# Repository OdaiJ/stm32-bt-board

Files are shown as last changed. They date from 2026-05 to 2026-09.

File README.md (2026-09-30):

# STM32 Bluetooth Demo Board

## Overview

A demo board I made as a project to learn PCB design fundamentals. The board is missing
some key features that make it general purpose; like headers for the unused MCU pins, however, it was a fun little project that took me a few months :)

This board was designed according to Phil's Lab's amazing videos on YouTube.

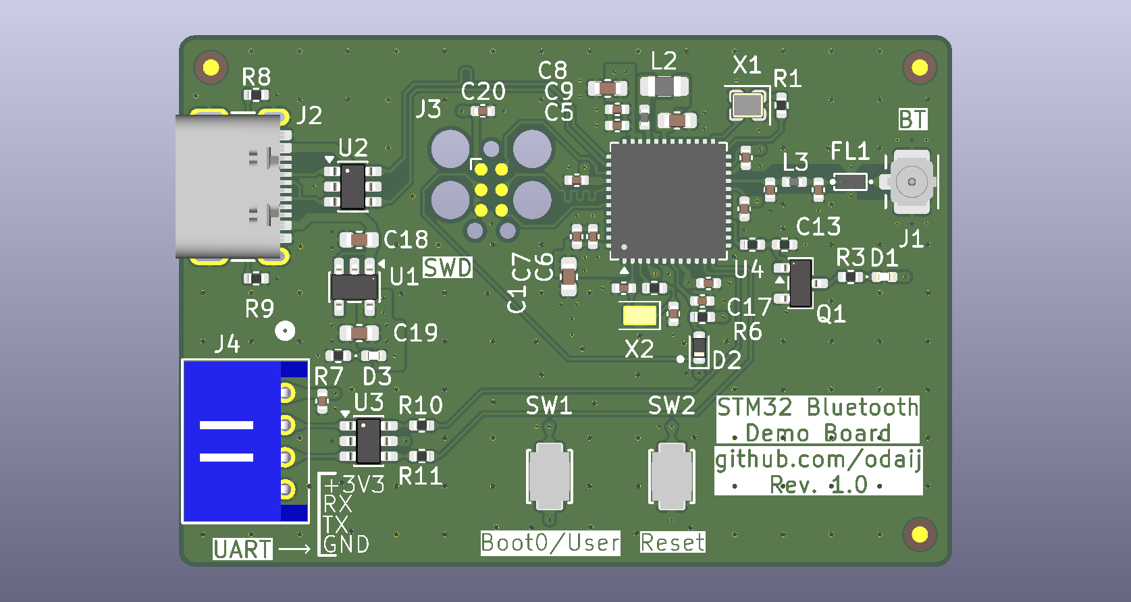
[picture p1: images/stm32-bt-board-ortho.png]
image depicting the top-down view of the board


Click here to view it on 

## Todos

1. More careful choice of components for BOM; as the MOQ is too high for most components as of now.

## Notes

Assembly PDFs are broken - KiCad won't export them correctly for some reason.

Also, as of now, I had to manually edit the CPL file so JLCPCB doesn't cry about it. P.S.: I do NOT recommend using the the JLCPCB Fabrication Tool KiCad plugin; because it didn't work for me - but that was probably my fault though.

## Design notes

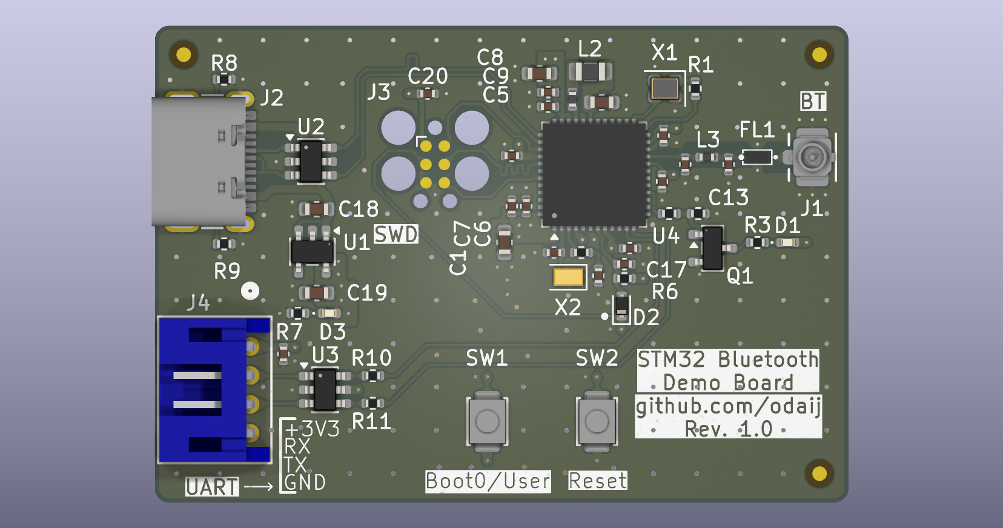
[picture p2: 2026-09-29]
images/stm32-bt-board-raytracing-ortho.png

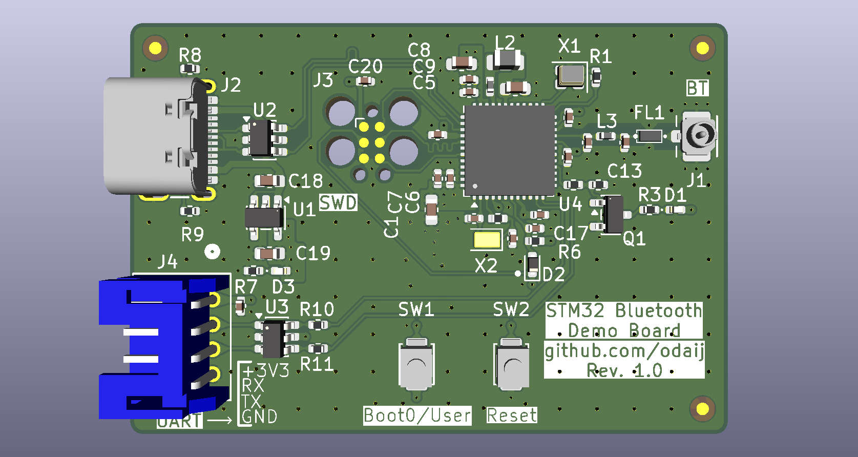
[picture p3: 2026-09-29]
images/stm32-bt-board.png

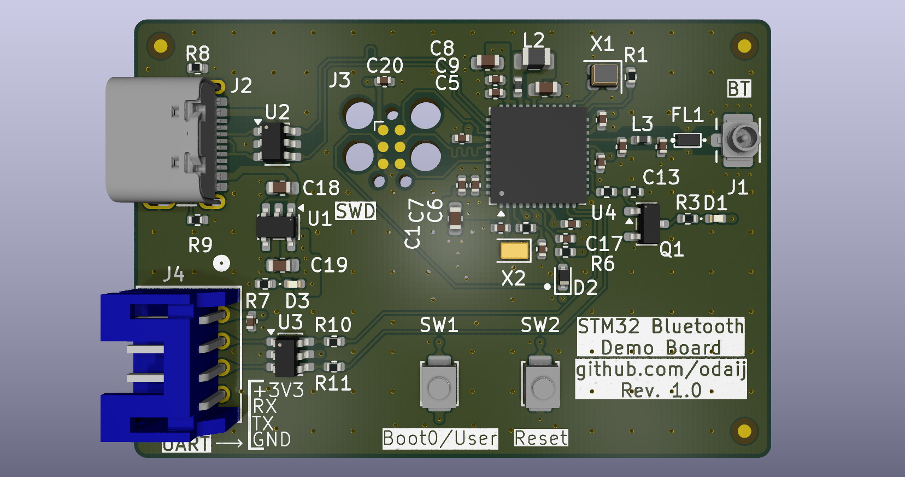
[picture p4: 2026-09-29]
images/stm32-bt-board-raytracing.png

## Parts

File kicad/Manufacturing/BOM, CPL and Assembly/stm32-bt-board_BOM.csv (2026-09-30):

Reference | Qty | Value | DNP | Exclude from BOM | Exclude from Board | Footprint | Datasheet | Distributor | Distributor Link | JLCPCB Part # | Manufacturer | MPN | Description
Q1 | 1 | S9013-E |  |  |  | Package_TO_SOT_SMD:SOT-23 | https://www.lcsc.com/datasheet/C41371419.pdf | LCSC | https://www.lcsc.com/product-detail/C41371419.html | C41371419 | MDD(Microdiode Semiconductor) | S9013-E | TRANS NPN 25V 0.5A SOT-23
X2 | 1 | 32kHz768 |  |  |  | Crystal:Crystal_SMD_2012-2Pin_2.0x1.2mm | https://www.lcsc.com/datasheet/C891748.pdf | LCSC | https://www.lcsc.com/product-detail/C891748.html | C891748 | NDK | NX2012SA-32.768KHZ-STD-MUB-2 | CRYSTAL 32.768kHz SMD
X1 | 1 | 32MHz |  |  |  | Crystal:Crystal_SMD_2016-4Pin_2.0x1.6mm | https://www.lcsc.com/datasheet/C5441424.pdf | LCSC | https://www.lcsc.com/product-detail/C5441424.html | C5441424 | NDK | NX2016SA-32MHZ-EXS00A-CS06654 | CRYSTAL 32MHz 8pF SMD
U4 | 1 | STM32WB55CEU6 |  |  |  | Package_DFN_QFN:QFN-48-1EP_7x7mm_P0.5mm_EP5.6x5.6mm | https://www.st.com/resource/en/datasheet/stm32wb55ce.pdf | LCSC | https://www.lcsc.com/product-detail/C911135.html | C911135 | ST | STM32WB55CEU6 | STMicroelectronics Arm Cortex-M4 MCU, 512KB flash, 256KB RAM, 64 MHz, 1.71-3.6V, 30 GPIO, UFQFPN48
U2,U3 | 2 | USBLC6-2SC6 |  |  |  | Package_TO_SOT_SMD:SOT-23-6 | https://www.st.com/resource/en/datasheet/usblc6-2.pdf | LCSC | https://www.lcsc.com/product-detail/C7519.html | C7519 | ST | USBLC6-2SC6 | Very low capacitance ESD protection diode, 2 data-line, SOT-23-6
U1 | 1 | MIC5365-3.3YD5 |  |  |  | Package_TO_SOT_SMD:TSOT-23-5 | https://ww1.microchip.com/downloads/aemDocuments/documents/APID/ProductDocuments/DataSheets/MIC5365-6-High-Performance-Single-150mA-LDO-DS20006605A.pdf | LCSC | https://www.lcsc.com/product-detail/C626098.html | C626098 | MICROCHIP | MIC5365-3.3YD5-TR | 150mA Low-dropout Voltage Regulator, Vout 3.3V, Vin up to 5.5V, TSOT-23-5
SW1,SW2 | 2 | B3U-1000P |  |  |  | #stm32-bt-board-external-footprints:B3U-1000P | https://www.lcsc.com/datasheet/C231329.pdf | LCSC | https://www.lcsc.com/product-detail/C231329.html | C231329 | OMRON | B3U-1000P | SWITCH TACTILE SPST 153gf SMD
R6 | 1 | 100k |  |  |  | Resistor_SMD:R_0402_1005Metric | https://www.lcsc.com/datasheet/C60491.pdf | LCSC | https://www.lcsc.com/product-detail/C60491.html | C60491 | YAGEO | RC0402FR-07100KL | RES 100kΩ ±1% 62.5mW 0402
R5,R8,R9,R13,R16 | 5 | 5k1 |  |  |  | Resistor_SMD:R_0402_1005Metric | https://www.lcsc.com/datasheet/C105872.pdf | LCSC | https://www.lcsc.com/product-detail/C105872.html | C105872 | YAGEO | RC0402FR-075K1L | RES 5.1kΩ ±1% 62.5mW 0402
R4,R7,R10,R11 | 4 | 220R |  |  |  | Resistor_SMD:R_0402_1005Metric | https://www.lcsc.com/datasheet/C2909336.pdf | LCSC | https://www.lcsc.com/product-detail/C2909336.html | C2909336 | FOJAN | FRC0402F2200TS | RES 220Ω ±1% 62.5mW 0402
R1,R2,R3 | 3 | 0R |  |  |  | Resistor_SMD:R_0402_1005Metric | https://www.lcsc.com/datasheet/C190119.pdf | LCSC | https://www.lcsc.com/product-detail/C190119.html | C190119 | VISHAY | CRCW04020000Z0ED | RES 0Ω 62.5mW 0402
L3 | 1 | 2n7 |  |  |  | Inductor_SMD:L_0402_1005Metric | https://www.lcsc.com/datasheet/C77108.pdf | LCSC | https://www.lcsc.com/product-detail/C77108.html | C77108 | muRata | LQG15HS2N7S02D | FIXED IND 2.7nH 800mA 120mΩ 0402
L2 | 1 | 10u |  |  |  | Inductor_SMD:L_0805_2012Metric | https://www.lcsc.com/datasheet/C162582.pdf | LCSC | https://www.lcsc.com/product-detail/C162582.html | C162582 | muRata | LQM21FN100M80L | FIXED IND 10uH 100mA 390mΩ 0805
L1 | 1 | 10n |  |  |  | Inductor_SMD:L_0402_1005Metric | https://www.lcsc.com/datasheet/C3911026.pdf | LCSC | https://www.lcsc.com/product-detail/C3911026.html | C3911026 | muRata | LQG15WZ10NJ02D | FIXED IND 10nH 500mA 190mΩ 0402
J4 | 1 | S4B-PH-K-S(LF)(SN) |  |  |  | #stm32-bt-board-external-footprints:S4B-PH-K-S(LF)(SN) | https://www.lcsc.com/datasheet/C157926.pdf | LCSC | https://www.lcsc.com/product-detail/C157926.html | C157926 | JST | S4B-PH-K-S(LF)(SN) | CONN HEADER TH R/A 4POS 2mm
J2 | 1 | 2171790001 |  |  |  | #stm32-bt-board-external-footprints:2171790001 | https://www.molex.com/content/dam/molex/molex-dot-com/products/automated/en-us/salesdrawingpdf/217/217179/2171790001_sd.pdf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\ | LCSC | https://www.lcsc.com/product-detail/C3197684.html | C3197684 | MOLEX | 2171790001 | TYPE C 16 PIN TOP MOUNT SMT
J1 | 1 | 1909763-1 |  |  |  | #stm32-bt-board-external-footprints:1909763-1 | https://www.lcsc.com/datasheet/C392444.pdf | LCSC | https://www.lcsc.com/product-detail/C392444.html | C392444 | TE Connectivity | 1909763-1 | CONN RCPT IPEX 50Ω SMD
FL1 | 1 | DLF162500LT-5028A1 |  |  |  | #stm32-bt-board-external-footprints:DLF162500LT-5028A1 | https://product.tdk.com/en/system/files/dam/doc/product/rf/rf/filter/catalog/rf_lpf_dlf162500lt-5028a1_en.pdf | LCSC | https://www.lcsc.com/product-detail/C531364.html | C531364 | TDK | DLF162500LT-5028A1 | Multilayer Low Pass Filter For 2400-2500MHz
D3 | 1 | VLMS1500-GS08 |  |  |  | LED_SMD:LED_0402_1005Metric | https://www.lcsc.com/datasheet/C511370.pdf | LCSC | https://www.lcsc.com/product-detail/C511370.html | C511370 | VISHAY | VLMS1500-GS08 | LED RED 0402 SMD
D2 | 1 | BAT54K |  |  |  | Diode_SMD:D_SOD-523 | https://www.lcsc.com/datasheet/C283259.pdf | LCSC | https://www.lcsc.com/product-detail/C283259.html | C283259 | ST | BAT54KFILM | DIODE SCHOTTKY 40V SOD-523
D1 | 1 | VLMB1500-GS08 |  |  |  | LED_SMD:LED_0402_1005Metric | https://www.lcsc.com/datasheet/C511042.pdf | LCSC | https://www.lcsc.com/product-detail/C511042.html | C511042 | VISHAY | VLMB1500-GS08 | LED BLUE 0402 SMD
C14,C15 | 2 | 10p |  |  |  | Capacitor_SMD:C_0402_1005Metric | https://www.lcsc.com/datasheet/C161520.pdf | LCSC | https://www.lcsc.com/product-detail/C161520.html | C161520 | muRata | GRM1555C1H100FA01D | CAP CER 10pF 50V C0G 0402
C13 | 1 | 0p3 |  |  |  | Capacitor_SMD:C_0402_1005Metric | https://www.lcsc.com/datasheet/C92338.pdf | LCSC | https://www.lcsc.com/product-detail/C92338.html | C92338 | muRata | GRM1555C1HR30WA01D | CAP CER 0.3pF 50V C0G 0402
C12 | 1 | 0p8 |  |  |  | Capacitor_SMD:C_0402_1005Metric | https://www.lcsc.com/datasheet/C76988.pdf | LCSC | https://www.lcsc.com/product-detail/C76988.html | C76988 | muRata | GRM1555C1HR80BA01D | CAP CER 0.8pF 50V C0G 0402
C2,C3,C4,C5,C6,C7,C9,C10,C16,C17,C20,C21 | 12 | 100n |  |  |  | Capacitor_SMD:C_0402_1005Metric | https://www.lcsc.com/datasheet/C60474.pdf | LCSC | https://www.lcsc.com/product-detail/C60474.html | C60474 | YAGEO | CC0402KRX7R7BB104 | CAP CER 100nF 16V X7R 0402
C1,C8,C11,C18,C19 | 5 | 4u7 |  |  |  | Capacitor_SMD:C_0603_1608Metric | https://www.lcsc.com/datasheet/C307467.pdf | LCSC | https://www.lcsc.com/product-detail/C307467.html | C307467 | Samsung Electro-Mechanics | CL10A475KL8NRNC | CAP CER 4.7uF 35V X5R 0603

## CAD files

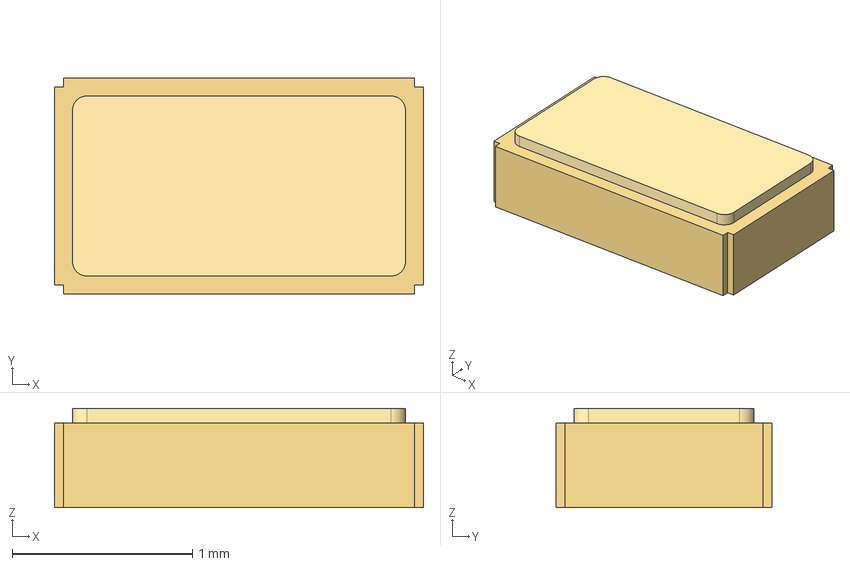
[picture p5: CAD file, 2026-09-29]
kicad/#stm32-bt-board-external-3d-models/NX2012SA-32.768KHZ-STD-MUB-2.step
2.05 x 1.20 x 0.55 mm
lid

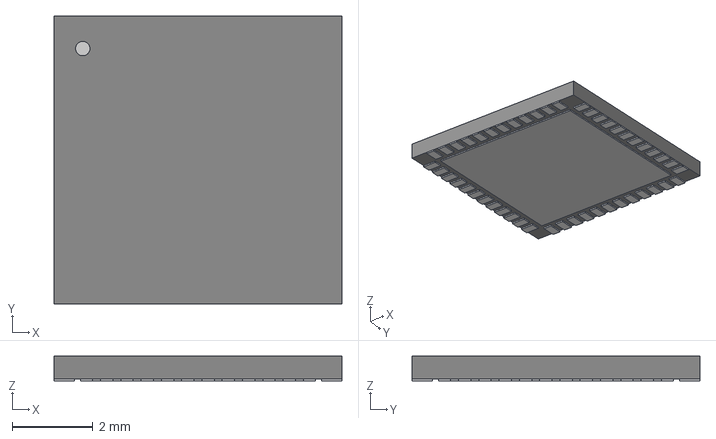
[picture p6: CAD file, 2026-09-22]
kicad/#stm32-bt-board-external-3d-models/STM32WB55CEU6.step
7.11 x 7.11 x 0.612 mm

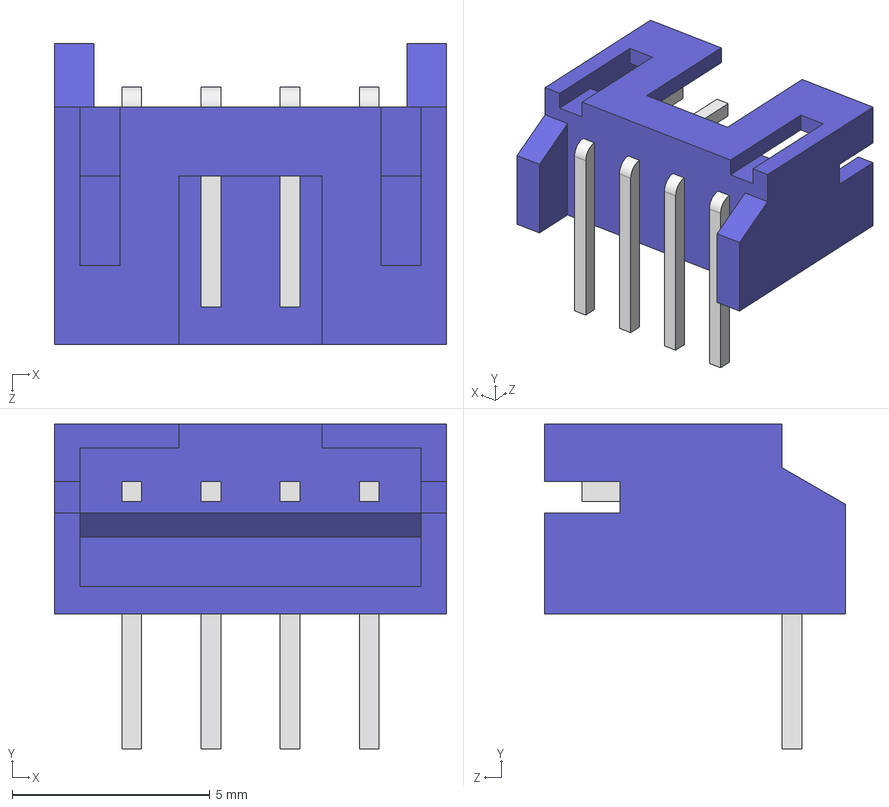
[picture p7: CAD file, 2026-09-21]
kicad/#stm32-bt-board-external-3d-models/S4B-PH-K-S(LF)(SN).STEP
9.90 x 8.20 x 7.60 mm

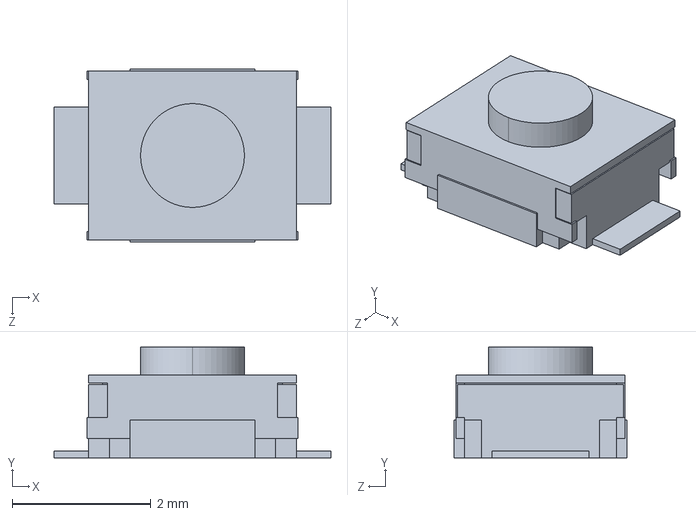
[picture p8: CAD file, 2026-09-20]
kicad/#stm32-bt-board-external-3d-models/B3U-1000P.step
4.00 x 1.60 x 2.50 mm

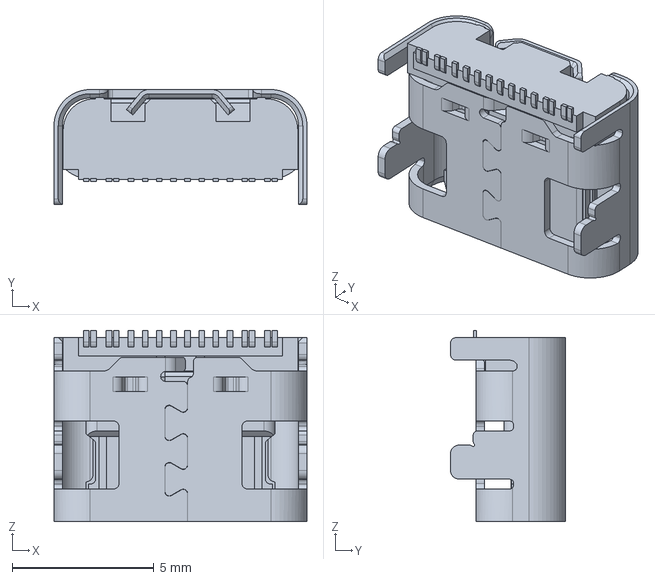
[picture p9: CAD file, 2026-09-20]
kicad/#stm32-bt-board-external-3d-models/2171790001.stp
8.94 x 4.06 x 6.75 mm

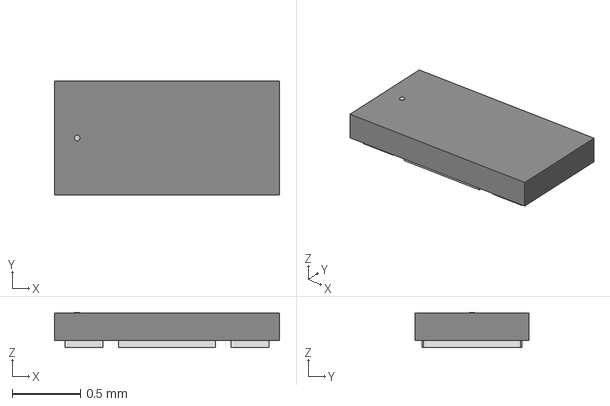
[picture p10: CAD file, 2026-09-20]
kicad/#stm32-bt-board-external-3d-models/DLF162500LT-5028A1.step
1.65 x 0.838 x 0.257 mm

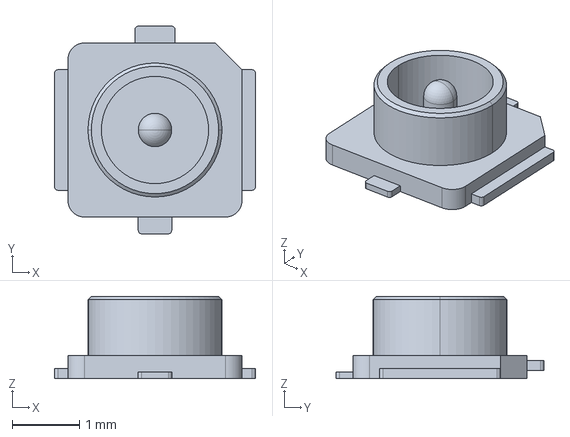
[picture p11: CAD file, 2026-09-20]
kicad/#stm32-bt-board-external-3d-models/1909763-1.stp
3.00 x 3.10 x 1.23 mm

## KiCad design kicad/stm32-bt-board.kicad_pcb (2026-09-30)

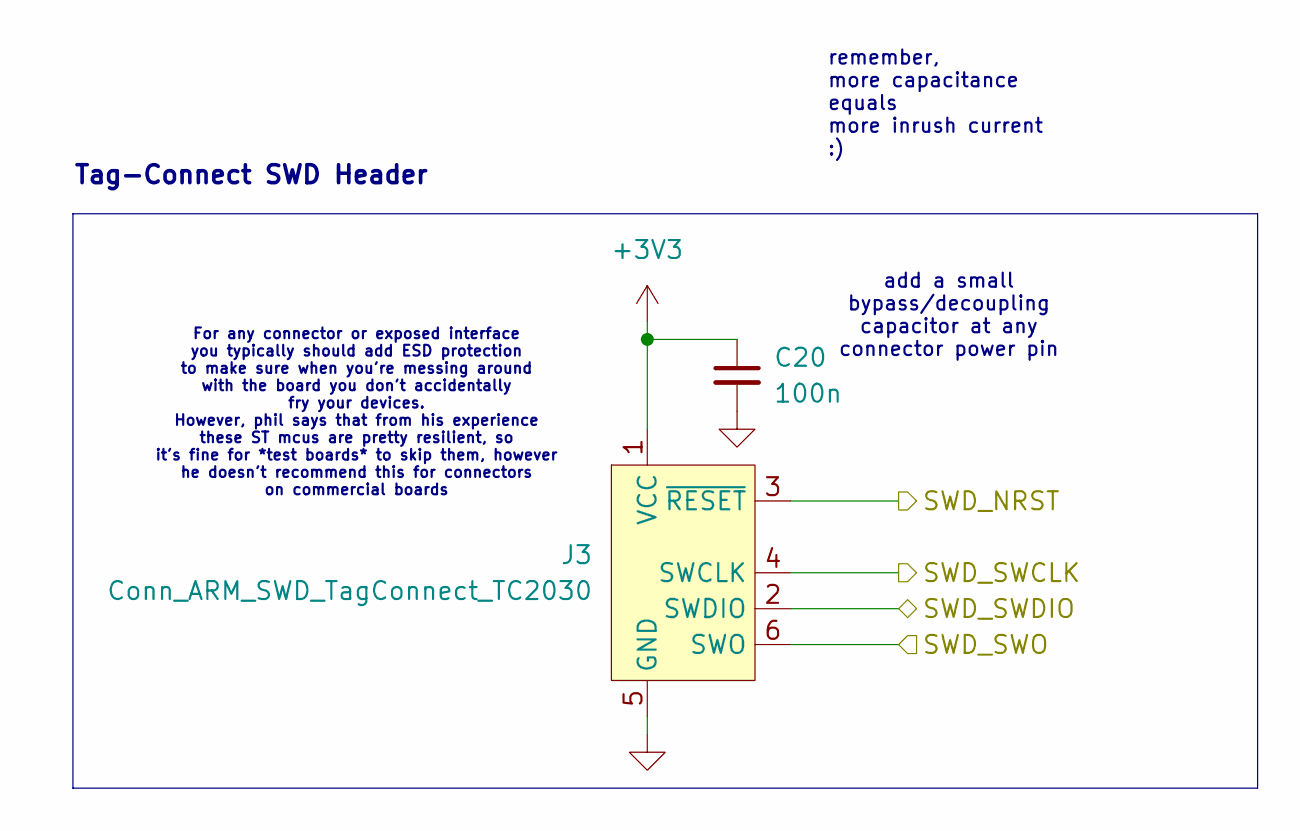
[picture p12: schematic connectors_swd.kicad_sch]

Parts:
C20: 100n; C_0402_1005Metric; MPN CC0402KRX7R7BB104
J3: Conn_ARM_SWD_TagConnect_TC2030; Tag-Connect_TC2030-IDC-FP_2x03_P1.27mm_Vertical

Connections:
+3V3: C20.1, J3.1 (VCC); also elsewhere on the board
/SWD_SWCLK: J3.4 (SWCLK); also elsewhere on the board
/SWD_SWDIO: J3.2 (SWDIO); also elsewhere on the board
/SWD_SWO: J3.6 (SWO); also elsewhere on the board
GND: C20.2, J3.5 (GND); also elsewhere on the board
NRST_IN: J3.3 (~RESET); also elsewhere on the board

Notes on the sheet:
remember, more capacitance equals more inrush current :)
For any connector or exposed interface you typically should add ESD protection to make sure when you're messing around with the board you don't accidentally fry your devices. However, phil says that from his experience these ST mcus are pretty resilient, so it's fine for *test boards* to skip them,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
Tag-Connect SWD Header
add a small bypass/decoupling capacitor at any connector power pin

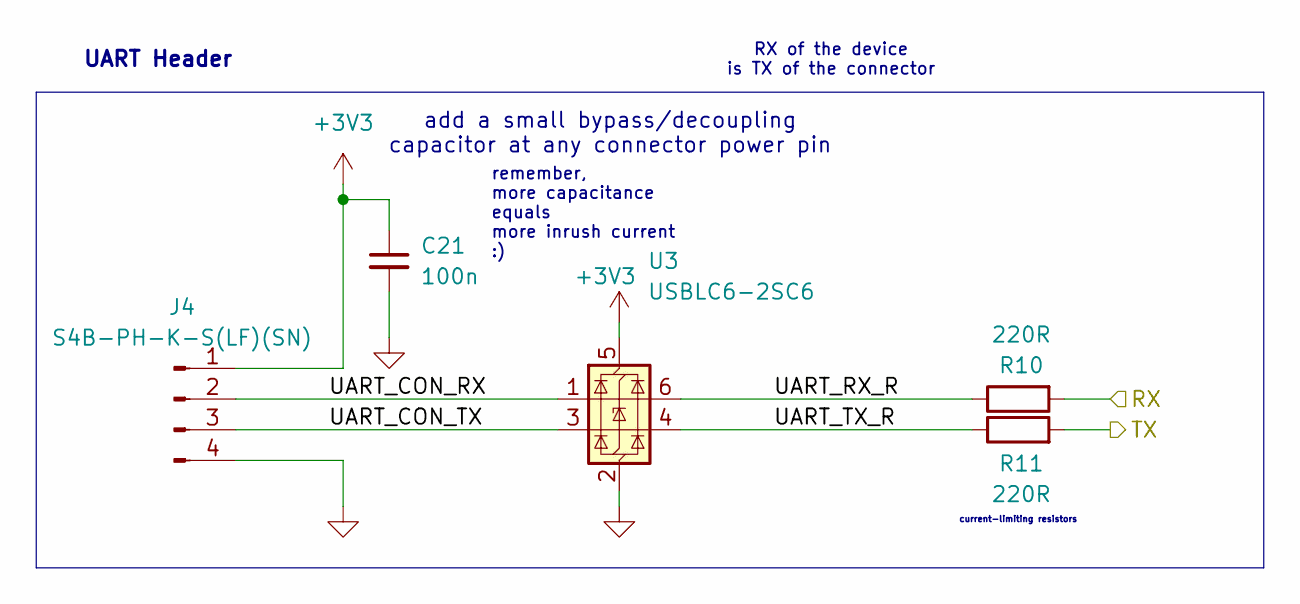
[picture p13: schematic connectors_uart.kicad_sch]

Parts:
C21: 100n; C_0402_1005Metric; MPN CC0402KRX7R7BB104
J4: S4B-PH-K-S(LF)(SN); MPN S4B-PH-K-S(LF)(SN)
R10, R11: 220R; R_0402_1005Metric; MPN FRC0402F2200TS
U3: USBLC6-2SC6; SOT-23-6; MPN USBLC6-2SC6

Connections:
+3V3: C21.1, J4.1, U3.5 (VBUS); also elsewhere on the board
/Connectors/UART/UART_CON_RX: J4.2, U3.1 (I/O1)
/Connectors/UART/UART_CON_TX: J4.3, U3.3 (I/O2)
/Connectors/UART/UART_RX_R: R10.1, U3.6 (I/O1)
/Connectors/UART/UART_TX_R: R11.1, U3.4 (I/O2)
/UART_MCU_RX: R11.2; also elsewhere on the board
/UART_MCU_TX: R10.2; also elsewhere on the board
GND: C21.2, J4.4, U3.2 (GND); also elsewhere on the board

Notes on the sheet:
remember, more capacitance equals more inrush current :)
add a small bypass/decoupling capacitor at any connector power pin
UART Header
RX of the device is TX of the connector
current-limiting resistors

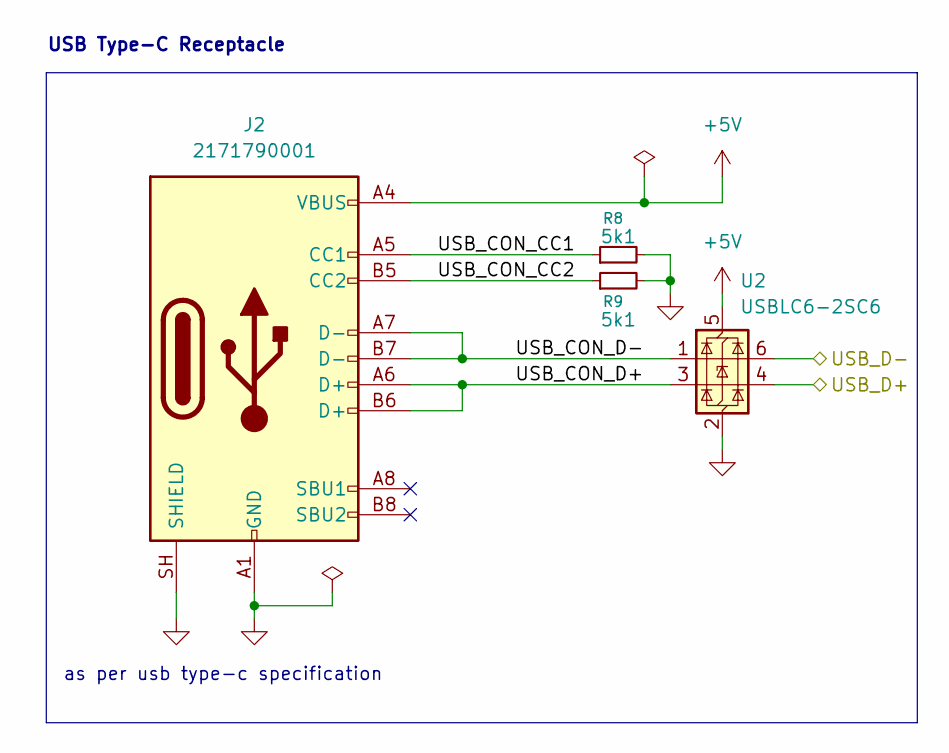
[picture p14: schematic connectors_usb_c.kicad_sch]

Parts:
J2: 2171790001; MPN 2171790001
R8, R9: 5k1; R_0402_1005Metric; MPN RC0402FR-075K1L
U2: USBLC6-2SC6; SOT-23-6; MPN USBLC6-2SC6

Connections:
+5V: J2.A4 (VBUS), J2.A9 (VBUS), J2.B4 (VBUS), J2.B9 (VBUS), U2.5 (VBUS); also elsewhere on the board
/Connectors/USB Type C/USB_CON_CC1: J2.A5 (CC1), R8.1
/Connectors/USB Type C/USB_CON_CC2: J2.B5 (CC2), R9.1
/Connectors/USB Type C/USB_CON_D+: J2.A6 (D+), J2.B6 (D+), U2.3 (I/O2)
/Connectors/USB Type C/USB_CON_D-: J2.A7 (D-), J2.B7 (D-), U2.1 (I/O1)
/USB_D+: U2.4 (I/O2); also elsewhere on the board
/USB_D-: U2.6 (I/O1); also elsewhere on the board
GND: J2.A1 (GND), J2.A12 (GND), J2.B1 (GND), J2.B12 (GND), J2.SH (SHIELD), R8.2, R9.2, U2.2 (GND); also elsewhere on the board

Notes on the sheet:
USB Type-C Receptacle
as per usb type-c specification

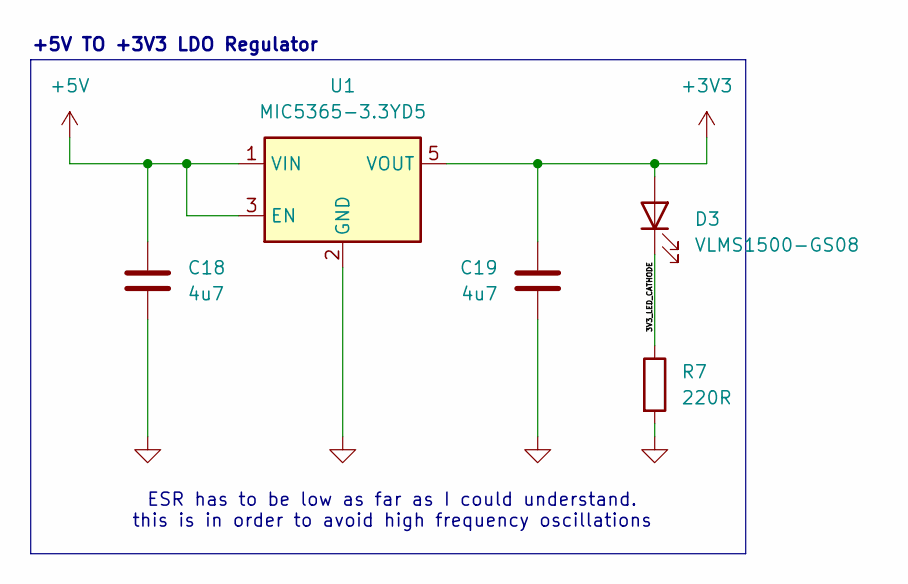
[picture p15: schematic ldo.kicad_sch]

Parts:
C18, C19: 4u7; C_0603_1608Metric; MPN CL10A475KL8NRNC
D3: VLMS1500-GS08; LED_0402_1005Metric; MPN VLMS1500-GS08
R7: 220R; R_0402_1005Metric; MPN FRC0402F2200TS
U1: MIC5365-3.3YD5; TSOT-23-5; MPN MIC5365-3.3YD5-TR

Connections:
+3V3: C19.1, D3.2 (A), U1.5 (VOUT); also elsewhere on the board
+5V: C18.1, U1.1 (VIN), U1.3 (EN); also elsewhere on the board
/LDO/3V3_LED_CATHODE: D3.1 (K), R7.1
GND: C18.2, C19.2, R7.2, U1.2 (GND); also elsewhere on the board

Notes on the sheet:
+5V TO +3V3 LDO Regulator
ESR has to be low as far as I could understand. this is in order to avoid high frequency oscillations

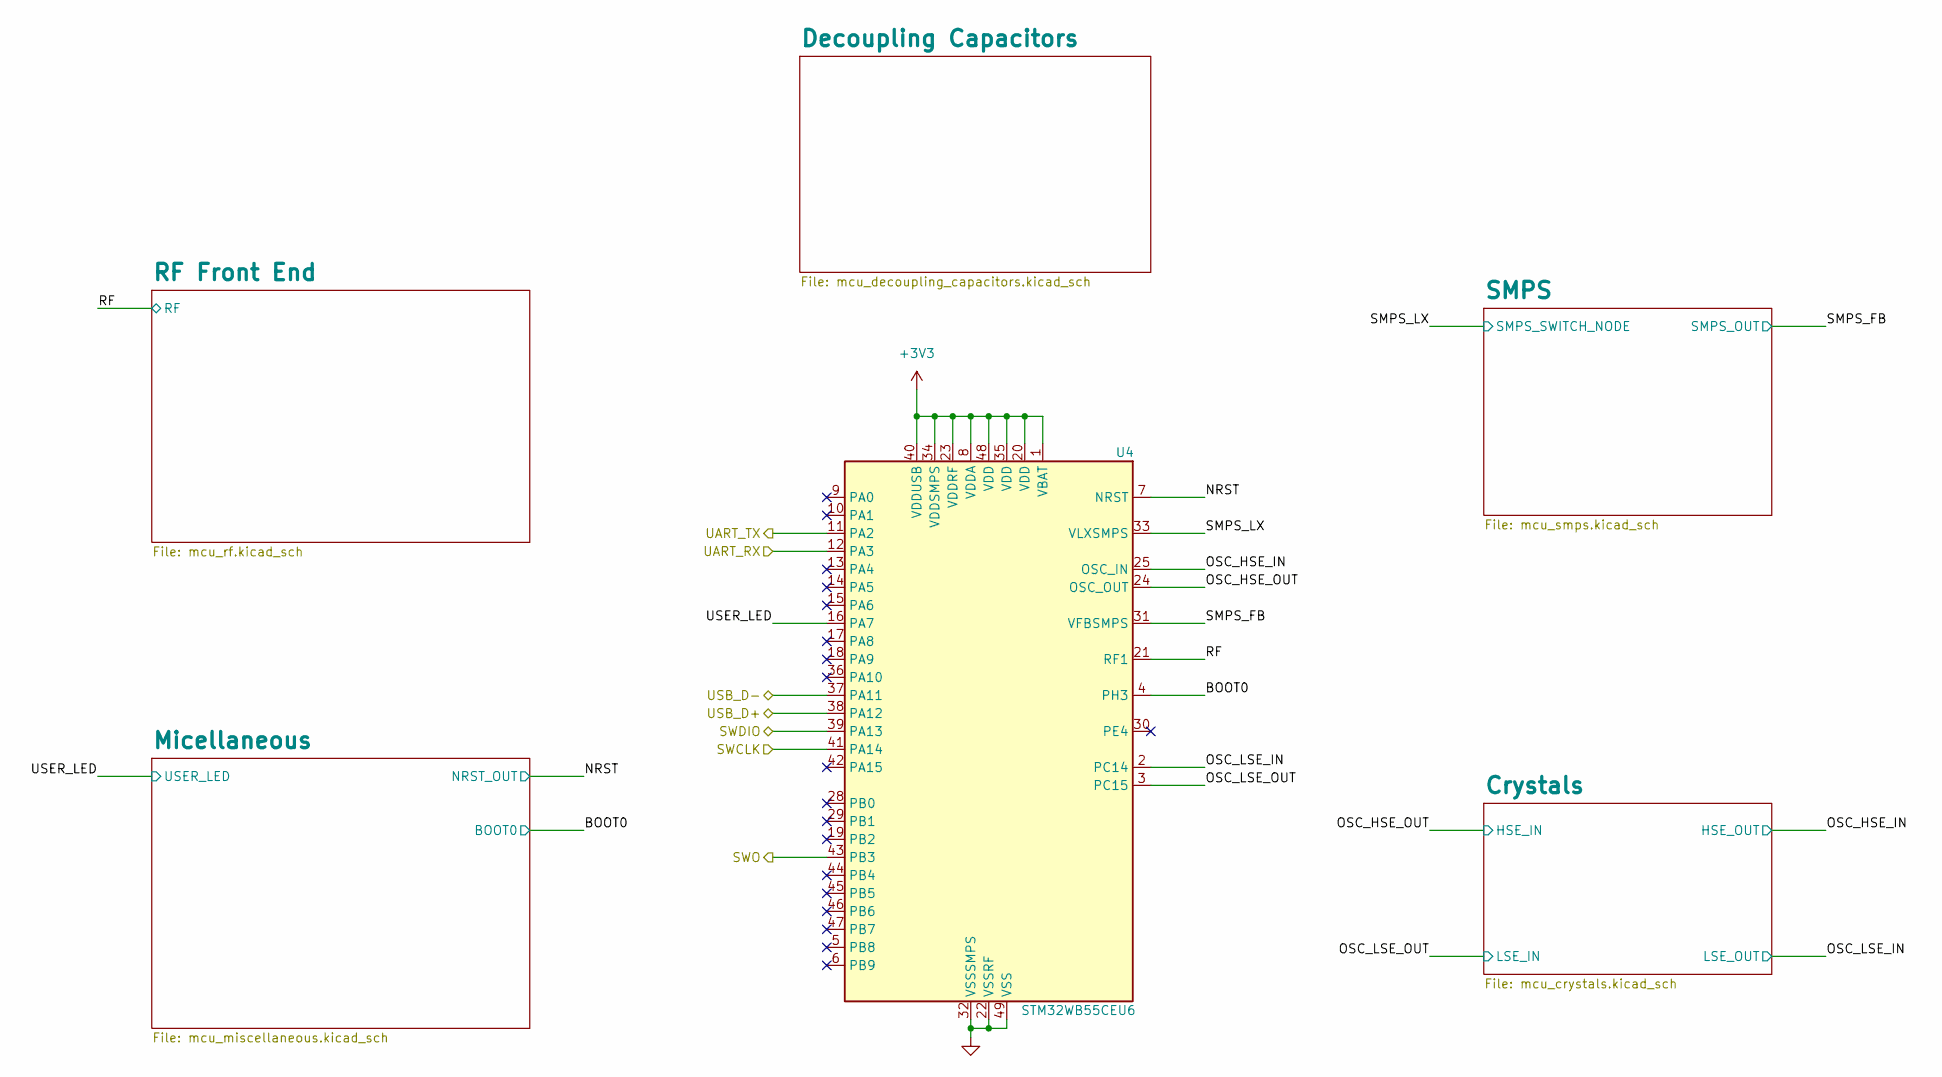
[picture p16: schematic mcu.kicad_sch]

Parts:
U4: STM32WB55CEU6; QFN-48-1EP_7x7mm_P0.5mm_EP5.6x5.6mm; MPN STM32WB55CEU6

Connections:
+3V3: U4.1 (VBAT), U4.8 (VDDA), U4.20 (VDD), U4.23 (VDDRF), U4.34 (VDDSMPS), U4.35 (VDD), U4.40 (VDDUSB), U4.48 (VDD); also elsewhere on the board
/Microcontroller/BOOT0: U4.4 (PH3); also elsewhere on the board
/Microcontroller/NRST: U4.7 (NRST); also elsewhere on the board
/Microcontroller/OSC_HSE_IN: U4.25 (OSC_IN); also elsewhere on the board
/Microcontroller/OSC_HSE_OUT: U4.24 (OSC_OUT); also elsewhere on the board
/Microcontroller/OSC_LSE_IN: U4.2 (PC14); also elsewhere on the board
/Microcontroller/OSC_LSE_OUT: U4.3 (PC15); also elsewhere on the board
/Microcontroller/RF: U4.21 (RF1); also elsewhere on the board
/Microcontroller/SMPS_FB: U4.31 (VFBSMPS); also elsewhere on the board
/Microcontroller/SMPS_LX: U4.33 (VLXSMPS); also elsewhere on the board
/Microcontroller/USER_LED: U4.16 (PA7); also elsewhere on the board
/SWD_SWCLK: U4.41 (PA14); also elsewhere on the board
/SWD_SWDIO: U4.39 (PA13); also elsewhere on the board
/SWD_SWO: U4.43 (PB3); also elsewhere on the board
/UART_MCU_RX: U4.12 (PA3); also elsewhere on the board
/UART_MCU_TX: U4.11 (PA2); also elsewhere on the board
/USB_D+: U4.38 (PA12); also elsewhere on the board
/USB_D-: U4.37 (PA11); also elsewhere on the board
GND: U4.22 (VSSRF), U4.32 (VSSSMPS), U4.49 (VSS); also elsewhere on the board

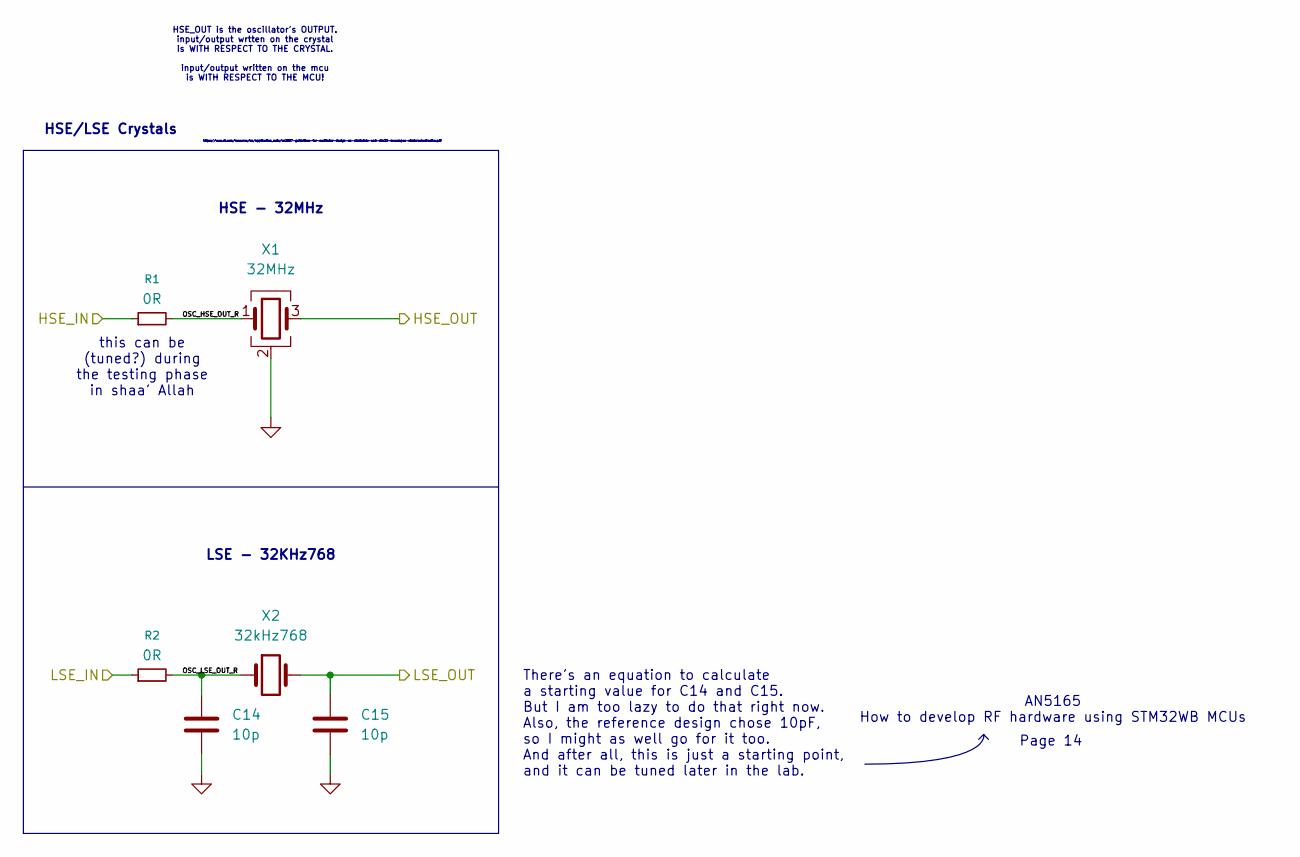
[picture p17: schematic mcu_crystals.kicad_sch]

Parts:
C14, C15: 10p; C_0402_1005Metric; MPN GRM1555C1H100FA01D
R1, R2: 0R; R_0402_1005Metric; MPN CRCW04020000Z0ED
X1: 32MHz; Crystal_SMD_2016-4Pin_2.0x1.6mm; MPN NX2016SA-32MHZ-EXS00A-CS06654
X2: 32kHz768; Crystal_SMD_2012-2Pin_2.0x1.2mm; MPN NX2012SA-32.768KHZ-STD-MUB-2

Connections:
/Microcontroller/Crystals/OSC_HSE_OUT_R: R1.2, X1.1
/Microcontroller/Crystals/OSC_LSE_OUT_R: C14.1, R2.2, X2.1
/Microcontroller/OSC_HSE_IN: X1.3; also elsewhere on the board
/Microcontroller/OSC_HSE_OUT: R1.1; also elsewhere on the board
/Microcontroller/OSC_LSE_IN: C15.1, X2.2; also elsewhere on the board
/Microcontroller/OSC_LSE_OUT: R2.1; also elsewhere on the board
GND: C14.2, C15.2, X1.2 (G), X1.4 (G); also elsewhere on the board

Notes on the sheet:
HSE/LSE Crystals
HSE - 32MHz
https://www.st.com/resource/en/application_note/an2867-guidelines-for-oscillator-design-on-stm8afals-and-stm32-mcusmpus-stmicroelectronics.pdf
LSE - 32KHz768
Page 14
AN5165 How to develop RF hardware using STM32WB MCUs
There's an equation to calculate a starting value for C14 and C15. But I am too lazy to do that right now. Also, the reference design chose 10pF, so I might as well go for it too. And after all, this is just a starting point, and it can be tuned later in the lab.
this can be (tuned?) during the testing phase in shaa' Allah
HSE_OUT is the oscillator's OUTPUT. input/output wrtten on the crystal is WITH RESPECT TO THE CRYSTAL. input/output written on the mcu is WITH RESPECT TO THE MCU!

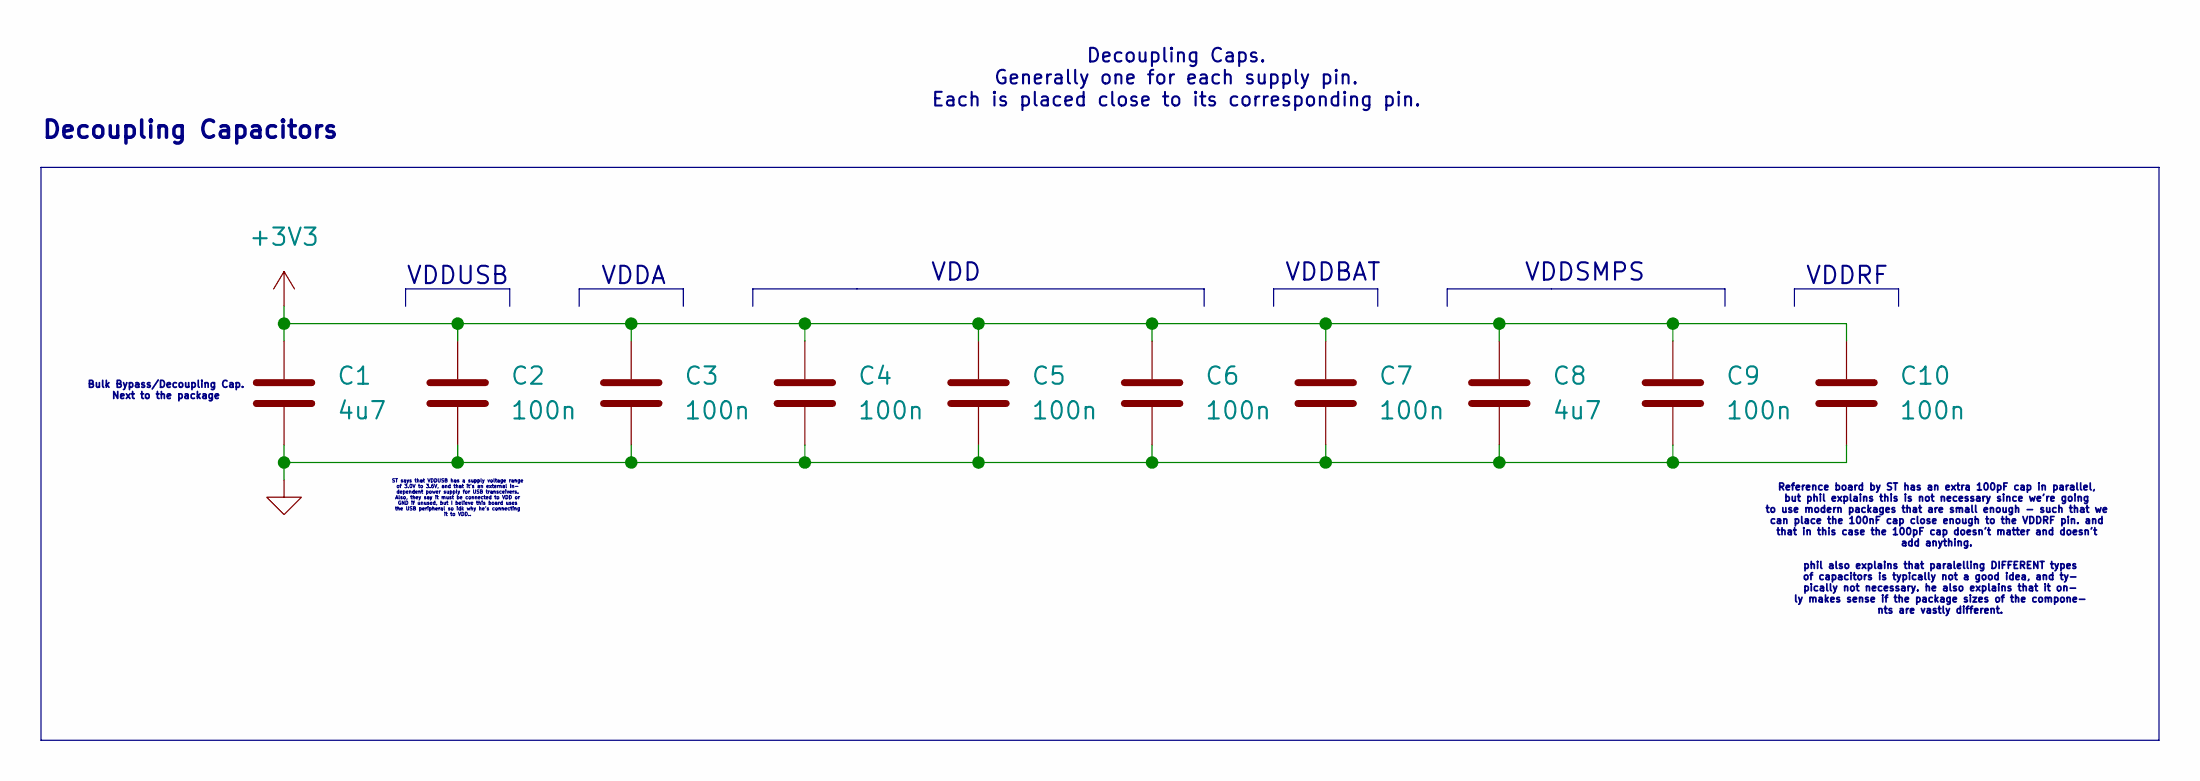
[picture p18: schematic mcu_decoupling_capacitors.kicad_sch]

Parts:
C1, C8: 4u7; C_0603_1608Metric; MPN CL10A475KL8NRNC
C2, C3, C4, C5, C6, C7, C9, C10: 100n; C_0402_1005Metric; MPN CC0402KRX7R7BB104

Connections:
+3V3: C1.1, C2.1, C3.1, C4.1, C5.1, C6.1, C7.1, C8.1, C9.1, C10.1; also elsewhere on the board
GND: C1.2, C2.2, C3.2, C4.2, C5.2, C6.2, C7.2, C8.2, C9.2, C10.2; also elsewhere on the board

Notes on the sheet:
VDDRF
VDD
Decoupling Caps. Generally one for each supply pin. Each is placed close to its corresponding pin.
Reference board by ST has an extra 100pF cap in parallel, but phil explains this is not necessary since we're going to use modern packages that are small enough - such that we can place the 100nF cap close enough to the VDDRF pin. and that in this case the 100pF cap doesn't matter and doesn't add a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
phil also explains that paralelling DIFFERENT types of capacitors is typically not a good idea, and ty- pically not necessary. he also explains that it on- ly makes sense if the package sizes of the compone- nts are vastly different.
Bulk Bypass/Decoupling Cap. Next to the package
Decoupling Capacitors
VDDBAT
VDDUSB
VDDA
ST says that VDDUSB has a supply voltage range of 3.0V to 3.6V, and that it's an external in- dependent power supply for USB transceivers. Also, they say it must be connected to VDD or GND if unused, but I believe this board uses the USB peripheral so idk why he's connecting it to VDD..
VDDSMPS

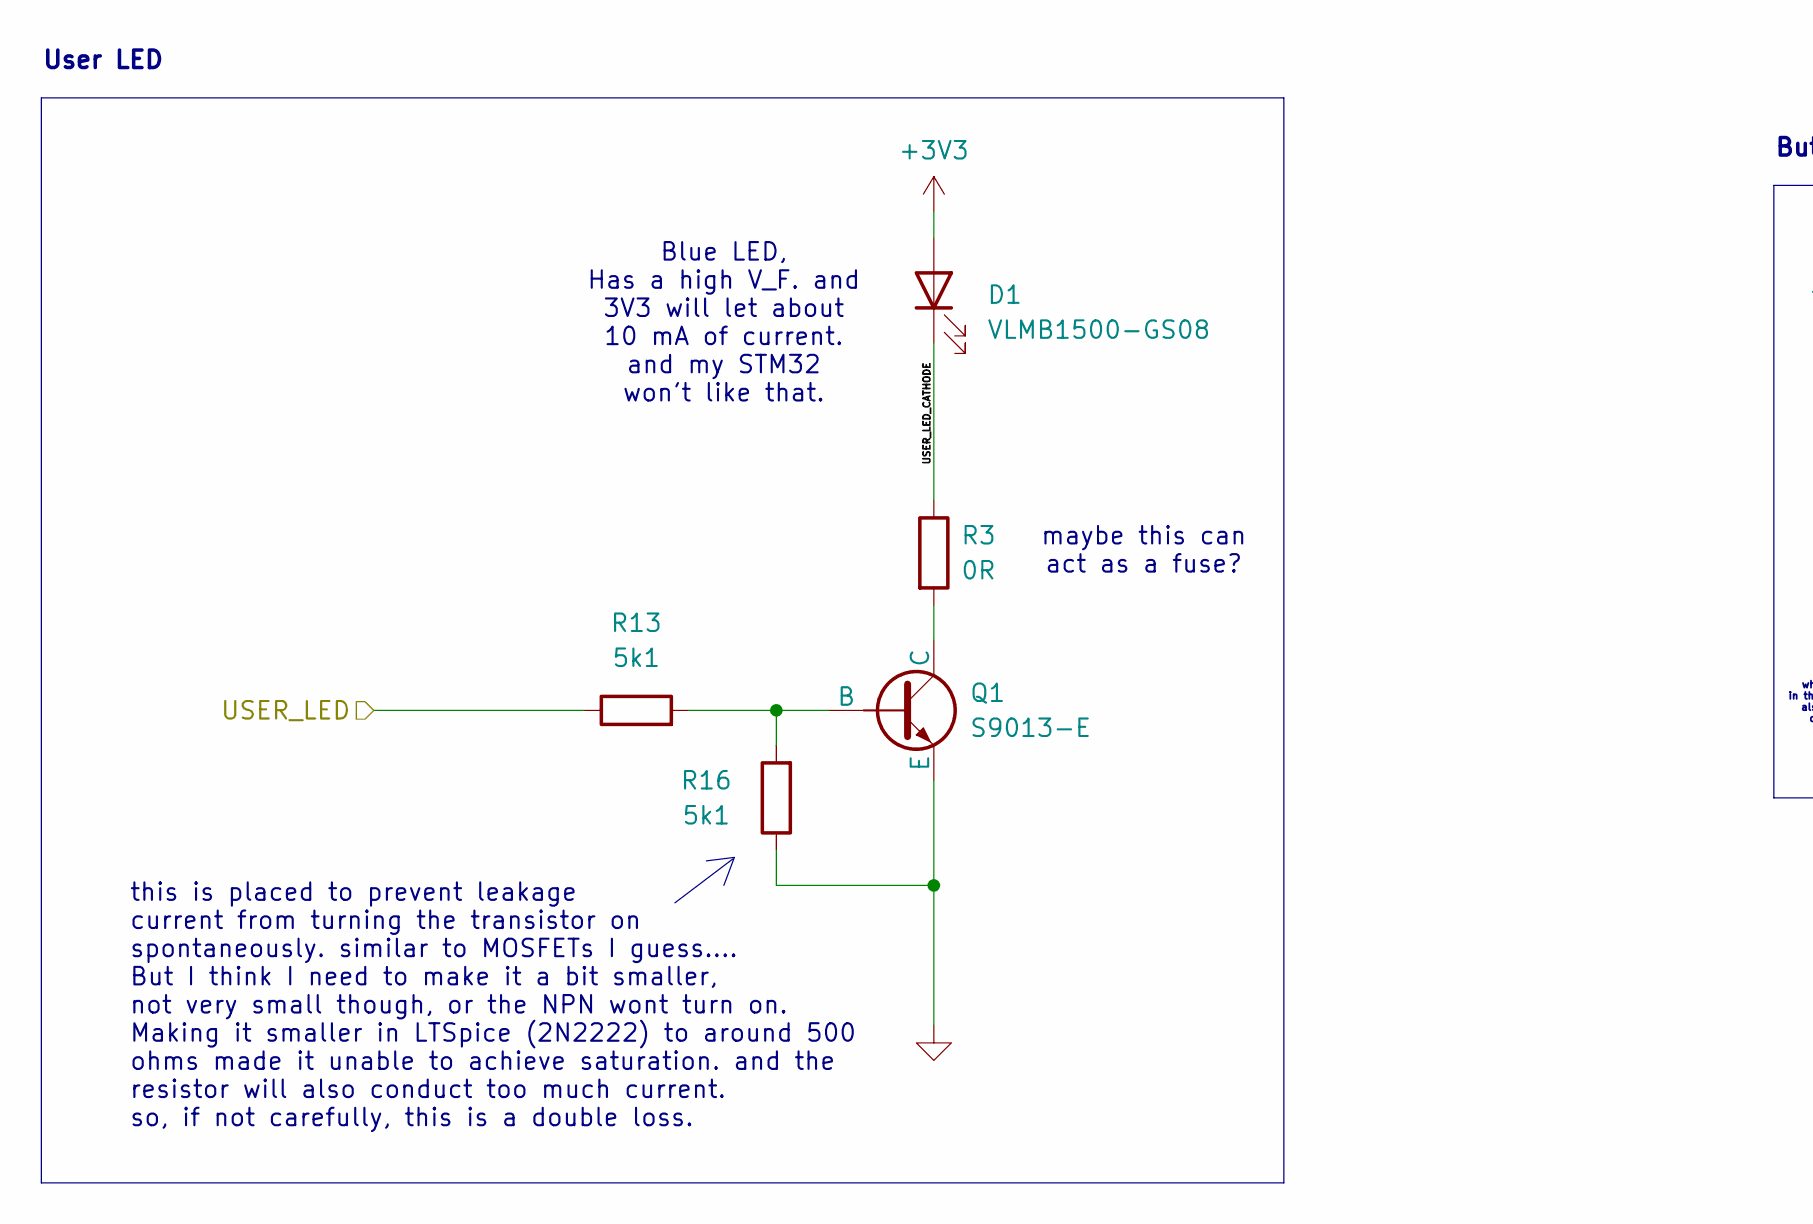
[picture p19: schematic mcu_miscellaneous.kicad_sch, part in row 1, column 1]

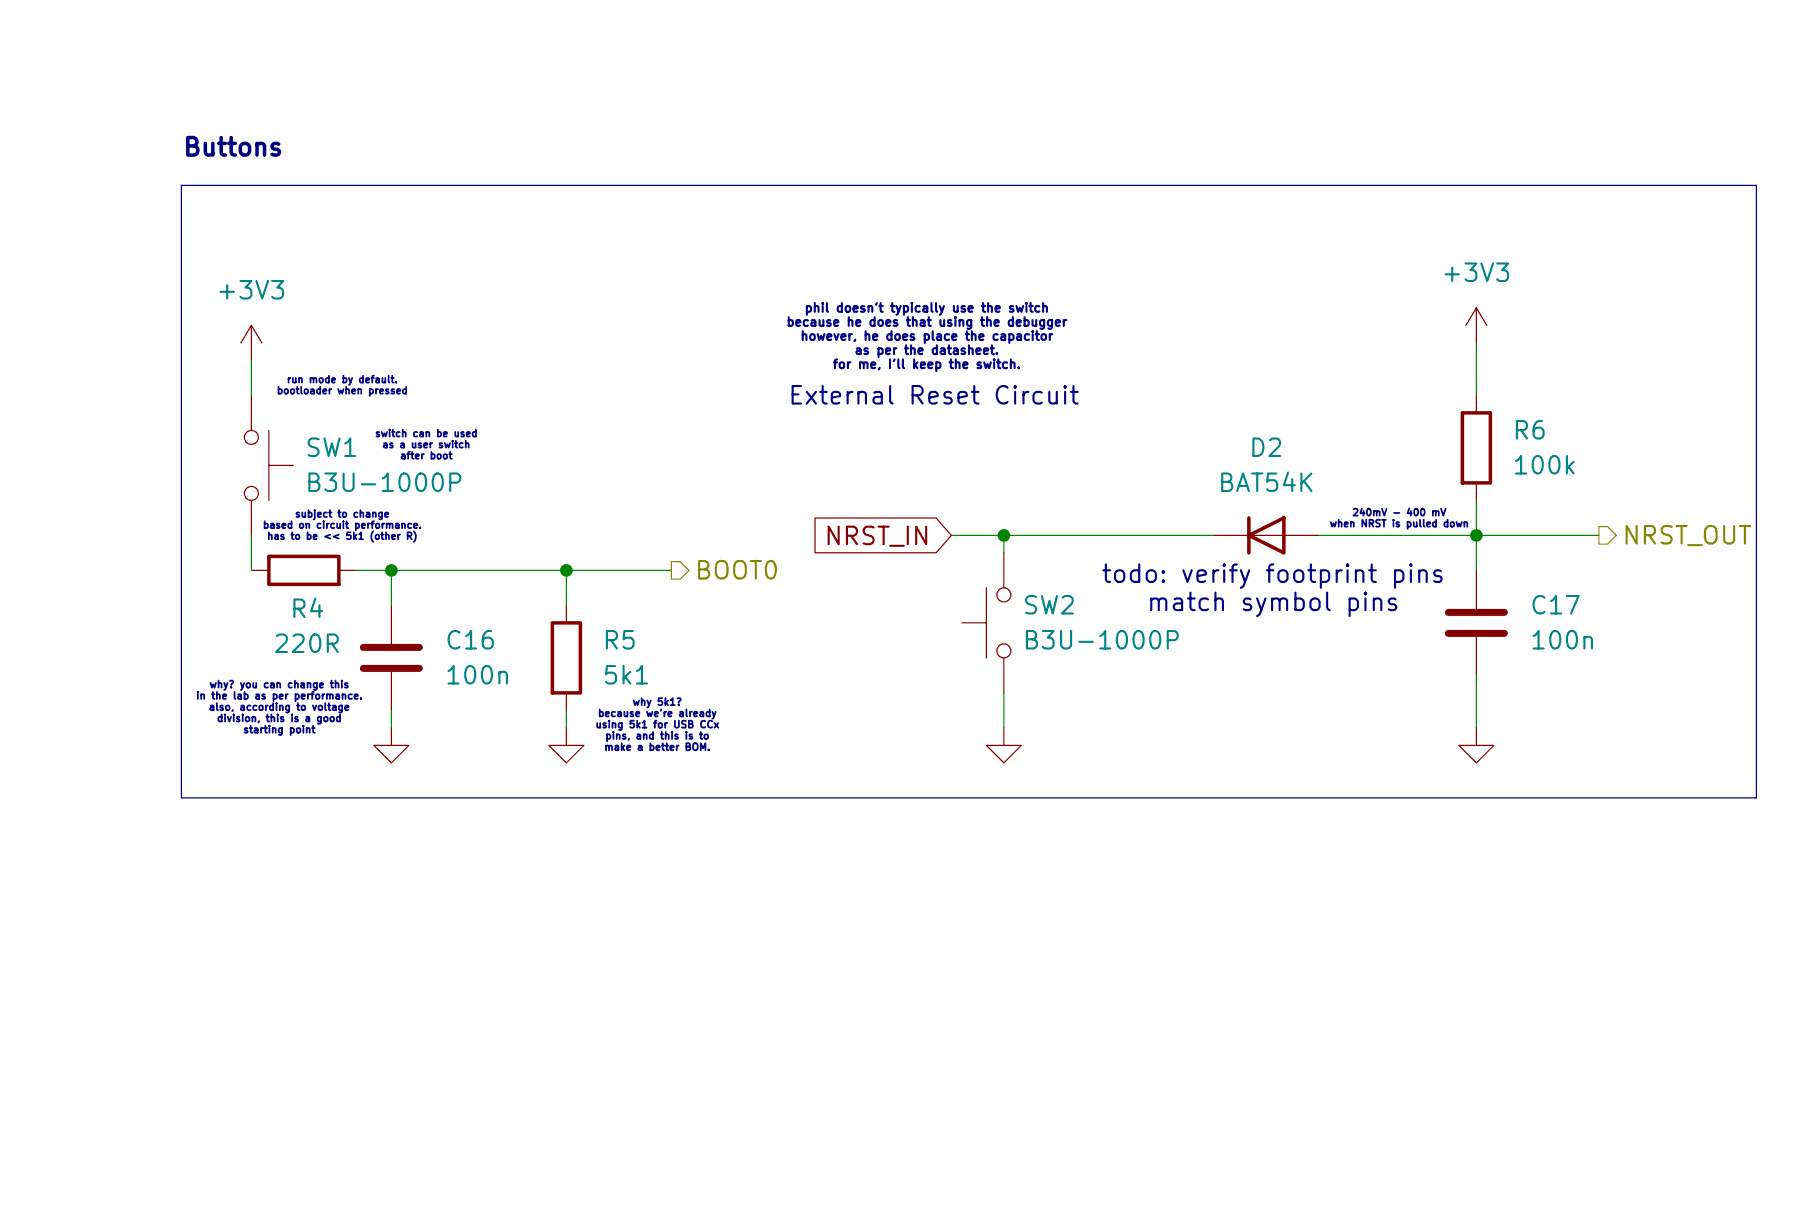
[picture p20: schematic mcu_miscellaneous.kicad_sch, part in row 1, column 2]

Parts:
C16, C17: 100n; C_0402_1005Metric; MPN CC0402KRX7R7BB104
D1: VLMB1500-GS08; LED_0402_1005Metric; MPN VLMB1500-GS08
D2: BAT54K; D_SOD-523; MPN BAT54KFILM
Q1: S9013-E; SOT-23; MPN S9013-E
R3: 0R; R_0402_1005Metric; MPN CRCW04020000Z0ED
R4: 220R; R_0402_1005Metric; MPN FRC0402F2200TS
R5, R13, R16: 5k1; R_0402_1005Metric; MPN RC0402FR-075K1L
R6: 100k; R_0402_1005Metric; MPN RC0402FR-07100KL
SW1, SW2: B3U-1000P; MPN B3U-1000P

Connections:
+3V3: D1.2 (A), R6.1, SW1.1; also elsewhere on the board
/Microcontroller/BOOT0: C16.1, R4.2, R5.1; also elsewhere on the board
/Microcontroller/Micellaneous/USER_LED_CATHODE: D1.1 (K), R3.1
/Microcontroller/NRST: C17.1, D2.2 (A), R6.2; also elsewhere on the board
/Microcontroller/USER_LED: R13.1; also elsewhere on the board
GND: C16.2, C17.2, Q1.2 (E), R5.2, R16.1, SW2.1; also elsewhere on the board
NRST_IN: D2.1 (K), SW2.2; also elsewhere on the board
unnamed: Q1.1 (B), R13.2, R16.2
unnamed: Q1.3 (C), R3.2
unnamed: R4.1, SW1.2

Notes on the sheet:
Buttons
External Reset Circuit
phil doesn't typically use the switch because he does that using the debugger however, he does place the capacitor as per the datasheet. for me, I'll keep the switch.
todo: verify footprint pins match symbol pins
Blue LED, Has a high V_F. and 3V3 will let about 10 mA of current. and my STM32 won't like that.
run mode by default. bootloader when pressed
240mV - 400 mV when NRST is pulled down
maybe this can act as a fuse?
why? you can change this in the lab as per performance. also, according to voltage division, this is a good starting point
why 5k1? because we're already using 5k1 for USB CCx pins, and this is to make a better BOM.
this is placed to prevent leakage current from turning the transistor on spontaneously. similar to MOSFETs I guess.... But I think I need to make it a bit smaller, not very small though, or the NPN wont turn on. Making it smaller in LTSpice (2N2222) to around 500 ohms made it unable to achieve satu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
subject to change based on circuit performance. has to be << 5k1 (other R)
switch can be used as a user switch after boot
User LED

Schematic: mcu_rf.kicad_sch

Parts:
C12: 0p8; C_0402_1005Metric; MPN GRM1555C1HR80BA01D
C13: 0p3; C_0402_1005Metric; MPN GRM1555C1HR30WA01D
FL1: DLF162500LT-5028A1; MPN DLF162500LT-5028A1
J1: 1909763-1; MPN 1909763-1
L3: 2n7; L_0402_1005Metric; MPN LQG15HS2N7S02D

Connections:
/Microcontroller/RF: C12.1, L3.1; also elsewhere on the board
/Microcontroller/RF Front End/RF_ANT: FL1.3 (OUT), J1.1 (In)
/Microcontroller/RF Front End/RF_MATCH: C13.1, FL1.1 (IN), L3.2
GND: C12.2, C13.2, FL1.2 (GND), FL1.4 (GND), J1.2 (Ext), J1.3 (Ext); also elsewhere on the board

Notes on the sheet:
50 Ohms Matching Network
RF Front-End
layout: careful layout needed? answer: yes

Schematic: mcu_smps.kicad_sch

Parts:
C11: 4u7; C_0603_1608Metric; MPN CL10A475KL8NRNC
L1: 10n; L_0402_1005Metric; MPN LQG15WZ10NJ02D
L2: 10u; L_0805_2012Metric; MPN LQM21FN100M80L

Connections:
/Microcontroller/SMPS/SMPS_LXL: L1.2, L2.1
/Microcontroller/SMPS_FB: C11.1, L2.2; also elsewhere on the board
/Microcontroller/SMPS_LX: L1.1; also elsewhere on the board
GND: C11.2; also elsewhere on the board

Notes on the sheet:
SMPS
AN5246 How to use SMPS to improve power efficiency on STM32WB MCUs

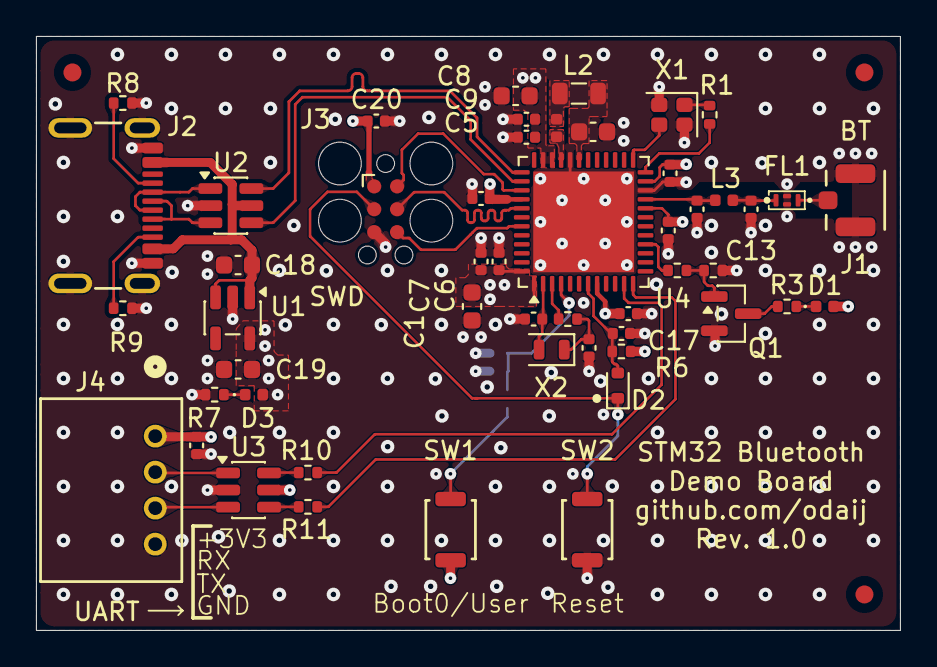
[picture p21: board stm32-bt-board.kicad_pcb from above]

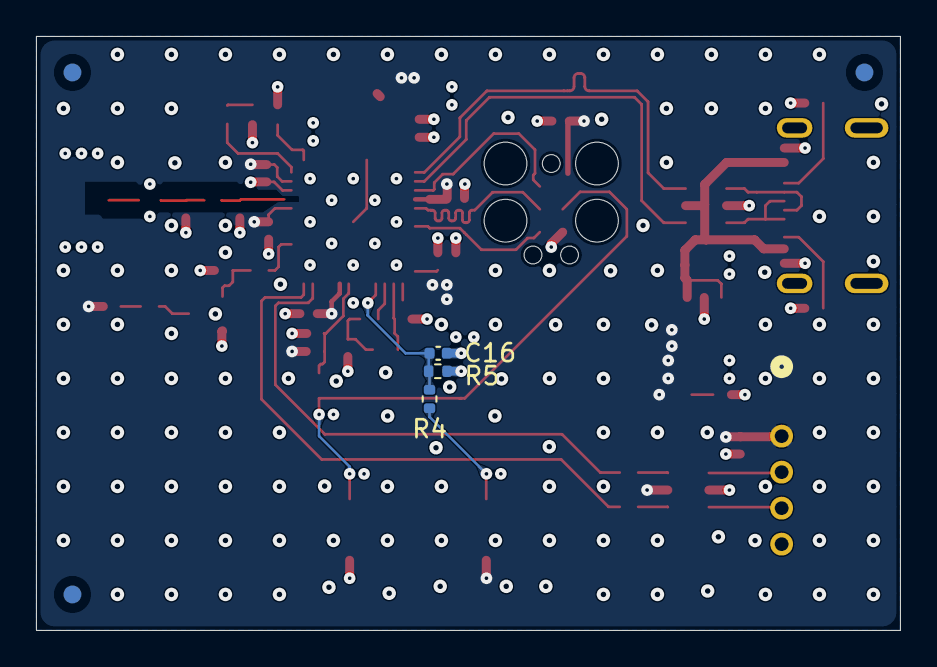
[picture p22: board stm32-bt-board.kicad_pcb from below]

Board: 4 copper layers, 48.0 x 33.0 mm, 60 parts (6 on the bottom side), 39 nets.

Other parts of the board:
FID1, FID2, FID3: Fiducial_1mm_Mask2mm
FID4, FID5, FID6: Fiducial; Fiducial_1mm_Mask2mm

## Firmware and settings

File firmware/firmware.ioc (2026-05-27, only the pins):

Mcu.UserName=STM32WB55CEUx
PA11.Signal=USB_DM
PA12.Signal=USB_DP
PA13.Signal=SYS_JTMS-SWDIO
PA14.Signal=SYS_JTCK-SWCLK
PA2.Signal=LPUART1_TX
PA3.Signal=LPUART1_RX
PA7.Signal=S_TIM17_CH1
PB3.Signal=SYS_JTDO-SWO
PC14-OSC32_IN.Signal=RCC_OSC32_IN
PC15-OSC32_OUT.Signal=RCC_OSC32_OUT

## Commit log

2026-05-15 chore: init
    [stm32-bt-board.kicad_pcb, stm32-bt-board.kicad_sch]
2026-05-16 feat(schematic): add hierarchical sheets, add STM32WB55CEUx power circuitry, and oscillator circuitry, and design notes
    add STM32WB55CEUx symbol and rename package variant suffix from X to 6 to explicitly target the "Industrial temperature range, -40 to 85 °C (105 °C junction)"
    add recommended MCU power decoupling network with a few tweaks following phil's video:
    - 100nF capacitor per VDD-related supply pin placed locally
    - 4.7uF bulk capacitors for VDD and VDDSMPS near the package
    add buck converter topology for the integrated SMPS, suitable for the 4MHz switching frequency, for best power performance
    add HSE and LSE crystal oscillator circuits (incomplete)
    add schematic notes and ref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
    [mcu.kicad_sch, stm32-bt-board.kicad_sch]
2026-05-22 feat(schematic): add RF, SWD, and core MCU support circuitry
    add unvalued capacitors for LSE crystal
    add TDK_DLF162500LT-5028A1 symbol, footprint, and an unverified 3D model
    add RF circuitry
    add SWD circuitry
    add BOOT0 circuitry
    add NRST circuitry
    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
    [mcu.kicad_sch]
2026-05-22 feat(firmware): add CubeMX configuration for hardware peripherals
    add hardware initializations for SWD, and crystal oscillators
    remove .gitkeep
    [firmware.ioc]
2026-05-23 feat (schematic): add basmala to root, create new hierarchical sheet for usb inside root, and more /stm32-bt-board/ add basmala to root schematic - add a new usb hierarchical sheet to root
    /stm32-bt-board/Microcontroller/
    - add resistance value for BOOT0 LPF
    /stm32-bt-board/USB/
    - add usb type c receptacle
    - add the usblc6-2sc6 protection ic to D- and D+
    - add 5k1 pull down resistors for CC1 and CC2
    [mcu.kicad_sch, stm32-bt-board.kicad_sch, usb.kicad_sch]
2026-05-27 A LOT OF STUFF
    I almost finished the schematic part of the tutorial
    what remains is part choosing and filling the relevant fields for every component
    [mcu.kicad_sch, mcu_crystals.kicad_sch, mcu_decoupling_capacitors.kicad_sch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]
2026-06-30 refactor(schematic): polish the schematic as much as possible - add new Basmala - fix netlist names almost EVERYWHERE, this is to help with net classes, and to help with building a good habit of nami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
    [connectors.kicad_sch, connectors_swd.kicad_sch, connectors_uart.kicad_sch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]
2026-07-19 fix(schematic:crystals): add the missing value for C12; 10pF
    [mcu_crystals.kicad_sch]
2026-07-31 fix(schematic): misc. fixes and stuff - sort all sheets - add the author's name to all sheets and update the date - add 0R resistor to the input of each crystal oscillator - reannotate all symbols - 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
    [connectors.kicad_sch, connectors_swd.kicad_sch, connectors_uart.kicad_sch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]
2026-09-17 everything: select real components, refactor schematic, add a user-led driving circuit, and more
    [connectors_swd.kicad_sch, connectors_uart.kicad_sch, connectors_usb_c.kicad_sch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]
2026-09-18 feat(components): add details
    [connectors_usb_c.kicad_sch, ldo.kicad_sch, mcu_miscellaneous.kicad_sch]
2026-09-20 fix(footprints and symbols): add missing footprints and symbols
    [1909763-1.stp, 2171790001.stp, B3U-1000P.step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]
2026-09-21 feat(layout): set up the board
    use JLCPCB's JLC04161H-3313 Stackup
    select board finish as HAL lead-free
    set up constraints and soldermask settings as per JLCPCB's capabilities page, and Phil's advice. the constraints need double checking though
    set up predefined sizes for general traces, and USB and Bluetooth traces according to JLCPCB's impedance calculator for non-coplanar single-ended and differential pair traces
    [stm32-bt-board.kicad_pcb]
2026-09-21 fix(3d models): remove unnecessary 3d model
    [NX2016SA-32MHZ-EXS00A-CS06654.step]
2026-09-21 feat(3d models): add 3d model for UART connector
    [S4B-PH-K-S(LF)(SN).STEP]
2026-09-21 fix(symbol): link TDK filter symbol to an existing footprint
    [mcu_rf.kicad_sch]
2026-09-21 feat(footprints): link footprints to existing footprints
2026-09-21 feat(layout): update layout from schematic
    [stm32-bt-board.kicad_pcb]
2026-09-21 refactor(schematic): update TODOs
    [stm32-bt-board.kicad_sch]
2026-09-22 feat(3d models): add 3d model for STM32WB55CEU6
    [STM32WB55CEU6.step]
2026-09-22 fix(schematic): fix connector-related errors
    change uart supply from +5V to +3V3
    change SWD netnames so net classes work properly
    [connectors.kicad_sch, connectors_swd.kicad_sch, connectors_uart.kicad_sch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]
2026-09-22 feat(schematic): add netname 'OSC_LSE_OUT_R' to LSE
    [mcu_crystals.kicad_sch]
2026-09-22 refactor(schematic): flip SW1 so layout is nicer
    [mcu_miscellaneous.kicad_sch]
2026-09-22 feat(layout): start a rough layout with netclasses
    [stm32-bt-board.kicad_pcb]
2026-09-22 refactor(layout): miscellaneous edits
    move components
    add github profile link
    add silkscreen for the 2 buttons; user and boot0
    [stm32-bt-board.kicad_pcb]
2026-09-26 feat(schematic:crystals): add netname after X1's resistor
    [mcu_crystals.kicad_sch]
2026-09-26 feat(layout & footprints): adjust layout and enhance custom footprints
    adjust decoupling capacitors' positions and almost everything else
    use rounded rectangular pads for all custom footprints, and update the pcb layout accordingly
    [stm32-bt-board.kicad_pcb]
2026-09-27 i am in a hurry
    [mcu_rf.kicad_sch, stm32-bt-board.kicad_pcb]
2026-09-28 feat(sch. and layout): add fiducial markers for front and back assembly
    [mechanical.kicad_sch, stm32-bt-board.kicad_sch]
2026-09-28 feat(layout): add vias, inner layer fills, and fully/partially route rf, usb, swd, uart, and power
    [stm32-bt-board.kicad_pcb]
2026-09-29 feat(layout): big update
    refine layout
    add missing vias
    complete routing
    remove skew between USB_D+ and USB_D-
    remove skew between SWD_SWCLK and SWD_SWDIO
    add stitching vias
    [stm32-bt-board.kicad_pcb]
2026-09-29 feat(layout): refine layout
    remove unused pads and vias using the built-in utility - keeping the outside pads there even if unused
    update D2 footprint to add a polarity dot of radius 0.2mm
    add guiding silkscreen for the connectors; RF, SWD, and UART
    [stm32-bt-board.kicad_pcb]
2026-09-29 feat(3d models): add 3d model for 32 kHz crystal
    [NX2012SA-32.768KHZ-STD-MUB-2.step]
2026-09-29 feat(BOM): fill missing parts in BOM
    [connectors_swd.kicad_sch, connectors_uart.kicad_sch, connectors_usb_c.kicad_sch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]
2026-09-29 feat(manuf.): extract bom, cpl, assembly and gerbers
    [stm32-bt-board-B_Cu.gbr, stm32-bt-board-B_Fab.gbr, stm32-bt-board-B_Mask.gbr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]
2026-09-29 fix(layout & manuf.): fix USB connector silkscreen and re-export gerbers (and drill files just to be safe)
    [stm32-bt-board-B_Cu.gbr, stm32-bt-board-B_Fab.gbr, stm32-bt-board-B_Mask.gbr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]
2026-09-29 fix(layout & manuf.): change stack up comment layer from F.Cu to User.Comments and re-export gerbers
    [stm32-bt-board-B_Cu.gbr, stm32-bt-board-B_Fab.gbr, stm32-bt-board-B_Mask.gbr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]
2026-09-30 chore(kicad): remove *.csv exclusion for BOM
2026-09-30 feat(layout & manuf.): add USB clearance and regenerate manufacturing files
    [stm32-bt-board-B_Cu.gbr, stm32-bt-board-B_Fab.gbr, stm32-bt-board-B_Mask.gbr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]
2026-09-30 feat(manuf.): edit BOM and CPL to match JLCPCB's requirements
    however, please pay close attention to the rotations during ordering, especially for the SOT components, as JLCPCB messes them up a bit, same for the connector and the filter
    [connectors_swd.kicad_sch, connectors_uart.kicad_sch, connectors_usb_c.kicad_sch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]
